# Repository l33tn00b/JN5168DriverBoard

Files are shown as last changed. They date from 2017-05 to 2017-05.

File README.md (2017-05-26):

# JN5168DriverBoard
Companion to JN5168 Carrier Board. Provides four nMOS FETs with FET drivers for boosting control voltage.

To be used for connecting LED strips or plain voltage driven LEDs. The chosen MOSFETs are rated up to 16A and give plenty of headroom (that is just another way of saying "...and are pretty much of an overkill"). While being logic level FETs, space for FET driver ICs is provided. So one may choose another FET (non-logic-level) in conjunction with the driver ICs. Or omit the driver ICs and go for the logic level FET. If you go towards the maximum rating of the FETs you might consider mounting the entire board on something suitable for heat dissipation. Normal operation at 20W per channel is not not much of a problem.

# Board Pictures (Prototypes)

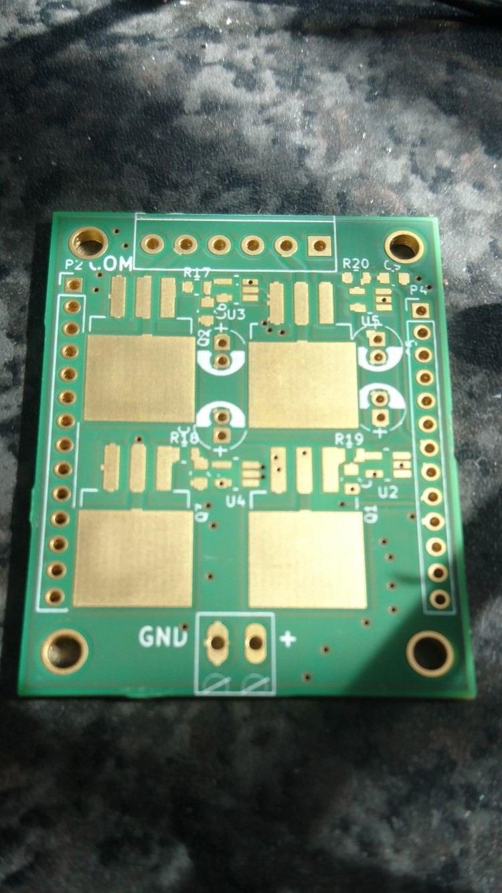
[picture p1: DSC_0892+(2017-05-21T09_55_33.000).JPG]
Raw Board


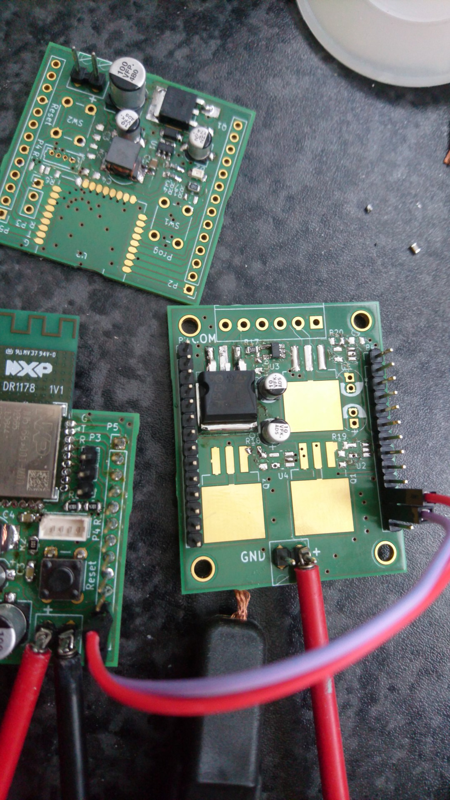
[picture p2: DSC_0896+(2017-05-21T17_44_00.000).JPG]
Parts for one channel in place together with JN5168 carrier board


Prototype boards shown here made by www.aisler.net (not affiliated in any way).

# Load Testing 

Load testing was performed using 10W resistors:

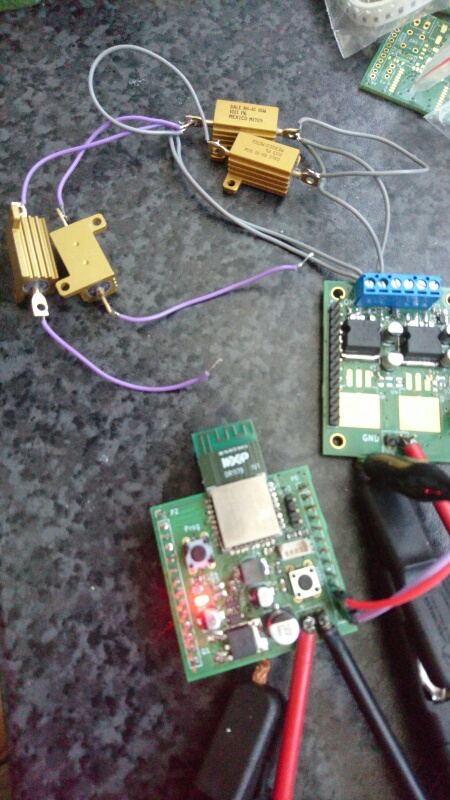
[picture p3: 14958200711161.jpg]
Load testing setup with 10W Dale resistors


# See also:

http://www.boriswerner.eu/tinkering-tuesday-hueify-pwm-to-rgb-led-strip-driver-board

https://peeveeone.com/?page_id=252

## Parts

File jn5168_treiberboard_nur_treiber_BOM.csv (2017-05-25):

Reference | Value | Footprint | Count | Datasheet | FootprintLib
CONN1 | RIACON-2 | con-riacon-RIACON-2 | 1 |  | riacon2_dixed
Q1,Q2,Q3,Q4 | STB16NF06LT4 | TO-263-3Lead | 4 |  | TO_SOT_Packages_SMD
U2,U3,U4,U5 | LTC1981 | SOT-23-5_HandSoldering | 4 |  | TO_SOT_Packages_SMD
C4,C2,C3,C5 | 10uF | CP_Elec_5x5.8 | 4 |  | Capacitors_SMD
R19,R17,R18,R20 | 1k | R_0805 | 4 |  | Resistors_SMD
P2 | CONN_01X14 | Pin_Header_Straight_1x14_Pitch2.54mm | 1 |  | Pin_Headers
P4 | CONN_01X13 | Pin_Header_Straight_1x13_Pitch2.54mm | 1 |  | Pin_Headers
P3 | CONN_01X06 | TerminalBlock_Pheonix_PT-3.5mm_6pol | 1 |  | Terminal_Blocks
R2,R4,R6,R8 | 10k | R_0805 | 4 |  | Resistors_SMD
R1,R3,R5,R7 | 0R | R_0805 | 4 |  | Resistors_SMD

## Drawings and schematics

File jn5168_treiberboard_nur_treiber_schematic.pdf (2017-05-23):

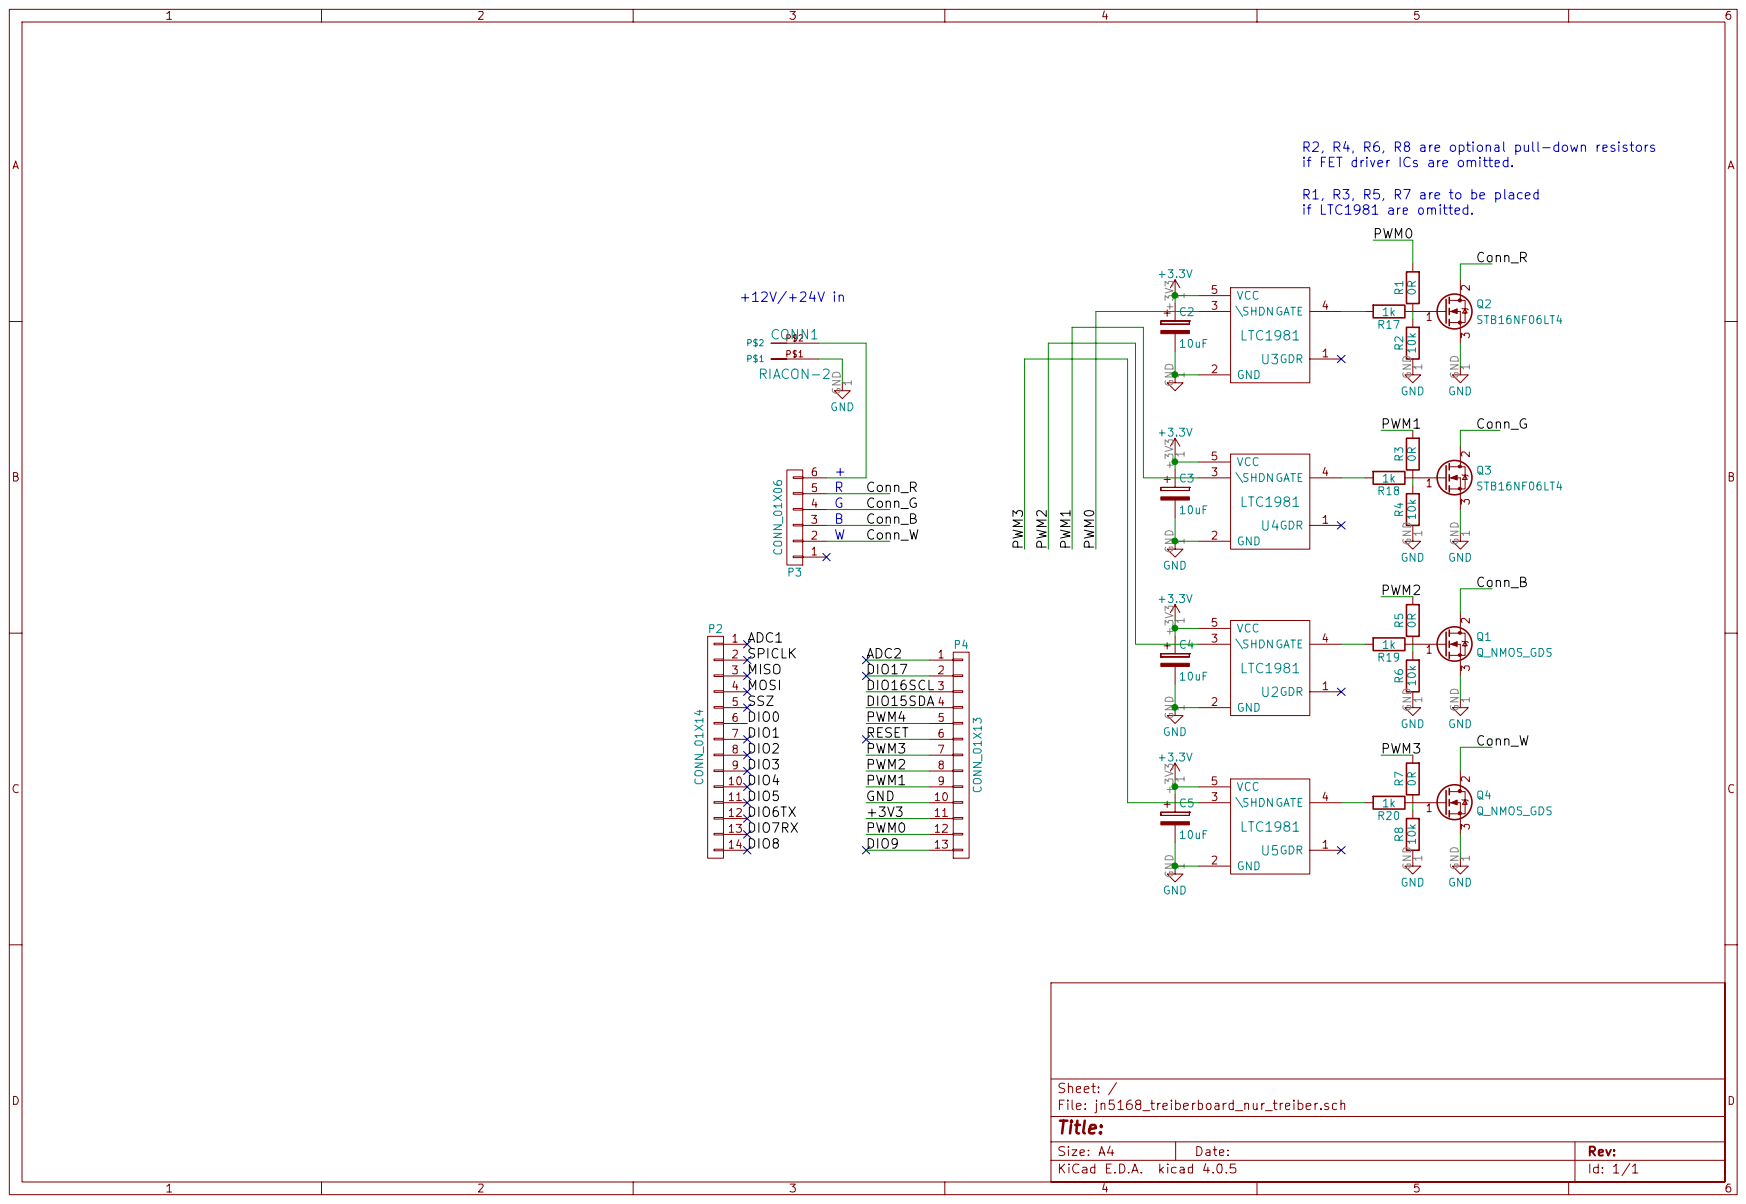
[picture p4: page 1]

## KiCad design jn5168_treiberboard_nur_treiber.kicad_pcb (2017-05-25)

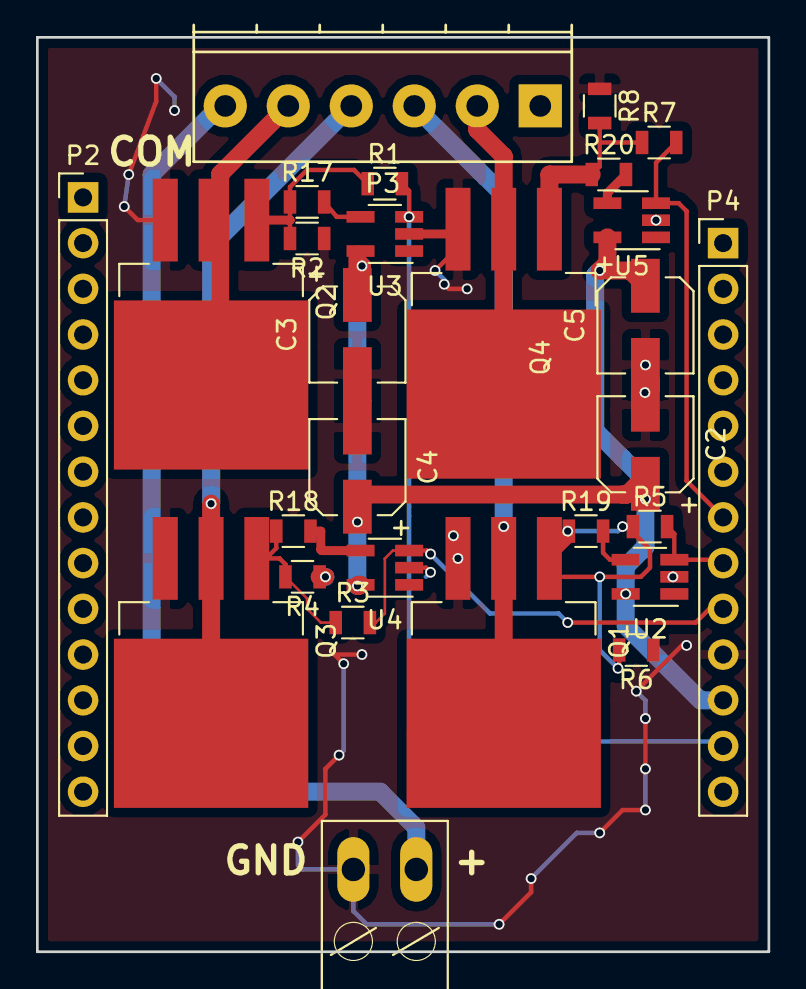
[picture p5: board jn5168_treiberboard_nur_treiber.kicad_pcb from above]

Board: 2 copper layers, 40.6 x 50.8 mm, 28 parts (0 on the bottom side), 19 nets.

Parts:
C2, C3, C4, C5: 10uF; CP_Elec_5x5.8
CONN1: RIACON-2; con-riacon-RIACON-2
P2: CONN_01X14; Pin_Header_Straight_1x14_Pitch2.54mm
P3: CONN_01X06; TerminalBlock_Pheonix_PT-3.5mm_6pol
P4: CONN_01X13; Pin_Header_Straight_1x13_Pitch2.54mm
Q1, Q2, Q3, Q4: STB16NF06LT4; TO-263-3Lead
R1, R3, R5, R7: 0R; R_0805
R2, R4, R6, R8: 10k; R_0805
R17, R18, R19, R20: 1k; R_0805
U2, U3, U4, U5: LTC1981; SOT-23-5_HandSoldering

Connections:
+3V3: C2.1, C3.1, C4.1, C5.1, P4.11, U2.5, U3.5, U4.5, U5.5
/Conn_B: P3.3, Q1.2
/Conn_G: P3.4, Q3.2
/Conn_R: P3.5, Q2.2
/Conn_W: P3.2, Q4.2
/PWM0: P4.12, R1.2, U3.3
/PWM1: P4.9, R3.2, U4.3
/PWM2: P4.8, R5.2, U2.3
/PWM3: P4.7, R7.2, U5.3
GND: C2.2, C3.2, C4.2, C5.2, CONN1.P$1, P4.10, Q1.3, Q2.3, Q3.3, Q4.3, R2.1, R4.1, R6.1, R8.1, U2.2, U3.2, U4.2, U5.2
unnamed: CONN1.P$2, P3.6
unnamed: Q1.1, R5.1, R6.2, R19.1
unnamed: Q2.1, R1.1, R2.2, R17.1
unnamed: Q3.1, R3.1, R4.2, R18.1
unnamed: Q4.1, R7.1, R8.2, R20.1
unnamed: R17.2, U3.4
unnamed: R18.2, U4.4
unnamed: R19.2, U2.4
unnamed: R20.2, U5.4

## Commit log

2017-05-23 Add files via upload
    PDF of schematic uploaded.
2017-05-25 Add files via upload
    BOM as HTML file
2017-05-25 Add files via upload
    BOM as euro-style .csv file.
    [jn5168_treiberboard_nur_treiber_BOM.csv]
2017-05-25 Add files via upload
    BOM as HTML file.
2017-05-25 Add files via upload
    Picture of PCB (no components placed).
2017-05-25 Add files via upload
    Picture of PCB. Components for one driver stage (plus an additional capacitor) have been placed. (Capacitors are SMD on through-hole places, bad hack ;) )
2017-05-25 Update README.md
    Insert link to Boris' site.
